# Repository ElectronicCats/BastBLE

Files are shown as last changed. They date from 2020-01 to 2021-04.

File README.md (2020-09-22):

# Bast BLE

Bast BLE is all the best in the world format Feather and BLE with a Nordic NRF!, Feather pin to pin compatible with a USB port type C.

Bast-BLE is supported in the Arduino development environment and Circuit Python coming soon

We love all our Feathers equally, but this Feather is very special. It's our first Feather that is specifically designed for use with CircuitPython! CircuitPython is our beginner-oriented flavor of MicroPython - and as the name hints at, its a small but full-featured version of the popular Python programming language specifically for use with circuitry and electronics.

Please note, CircuitPython does not come preloaded. See the full guide linked below for instructions on installing it

Lipoly battery and USB cable not included (but we do have lots of options in the shop if you'd like!)

## Hardware Features

* Nordic nRF52840 System-on-Chip
	- ARM® Cortex®-M4F processor optimized for ultra-low power operation
	- Combining *Bluetooth 5*, *Bluetooth Mesh*, *Thread*, *IEEE 802.15.4*, *ANT* and *2.4GHz proprietary*
	- On-chip NFC-A tag
	- On-chip USB 2.0 (Full speed) controller
	- ARM TrustZone® Cryptocell 310 security subsystem
	- 1 MB FLASH and 256 kB RAM
* Program/Debug options with DAPLink
	- MSC - drag-n-drop programming flash memory
	- CDC - virtual com port for log, trace and terminal emulation
	- HID - CMSIS-DAP compliant debug channel
	- WEBUSB HID - CMSIS-DAP compliant debug channel
* External ultra-low power 64-Mb QSPI FLASH memory
* Up to 21 GPIOs available via headers
* IF Boot/Reset Button
* On-board 2.4G chip antenna 
* 3.3V regulator with 1A peak current output
* VBUS & VIN Power-Path Management
* Reversible USB 3.1 Type-C Connector
* Breadboard-friendly with dual 18-Pin headers
* Feather Format

## How to get Bast BLE
Bast BLE is available on the following channels (click to go directly to the product):

<a href="https://electroniccats.com/store/nfc-copy-cat/">
  
</a>

## Pinout Diagram
Coming Soon..
[]()

## Software Resource

The nRF52840 Micro Dev Kit USB Dongle can be used to play with : *nRF5 SDK*, *OpenThread*, *Web Bluetooth*, *iBeacon*, *Eddystone*, and more.

| Software  | Brief Description |
| --- | ----- |
| [Arduino Core MbedOS](https://github.com/ElectronicCats/ArduinoCore-mbed) | The friendly Arduino core by Electronic Cats with MbedOS, |
| [UF2 Bootloader](https://github.com/ElectronicCats/Adafruit_nRF52_Bootloader) | UF2 Bootloader fir NRF52, |
| [nRF5 SDK](nrf5-sdk/) | Offical Software Development Kit for nRF51 and nRF52 Series |
| [OpenThread Border Router](OTBR/) | An open source border router, designed to work with OpenThread |
| [Thread Network Sniffer](thread-sniffer/) | Help you to efficiently analyze Thread network traffic|
| [Web Bluetooth](https://webbluetoothcg.github.io/web-bluetooth/) | Bluetooth support for the Web |
| [iBeacon](https://developer.apple.com/ibeacon/) | A Bluetooth low energy advertising message format designed by Apple |
| [Eddystone](https://github.com/google/eddystone) | A protocol specification that defines a Bluetooth low energy message format for proximity beacon messages |
| [CircuitPython](https://github.com/adafruit/circuitpython/blob/master/ports/nrf/README.md) | A Python language for microcontrollers designed to simplify experimentation and learning |
| [TinyGo](https://github.com/tinygo-org/tinygo) | Go compiler for small devices, based on LLVM |
| [Rust for nrf52840-mdk](https://github.com/nrf-rs/nrf52840-mdk-rs) | Rust support for the nrf52840-mdk development board |
| [RIOT OS](https://github.com/RIOT-OS/RIOT/blob/695e91a90a6545b6937bd0f52f0e87d278155ec0/boards/nrf52840-mdk/doc.txt) | The friendly Operating System for the Internet of Things, |

## Contributing

We would love for you to contribute to this project and help make it even better than it is today! 

License

OpenSourceLicense

Electronic Cats invests time and resources providing this open source design, please support Electronic Cats and open-source hardware by purchasing products from Electronic Cats!

Designed by Electronic Cats.

Firmware released under an GNU AGPL v3.0 license. See the LICENSE file for more information.

Hardware released under an CERN Open Hardware Licence v1.2. See the LICENSE_HARDWARE file for more information.

Electronic Cats is a registered trademark, please do not use if you sell these PCBs.

January 2020

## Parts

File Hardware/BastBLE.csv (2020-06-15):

Reference | Quantity | Value | Footprint | Datasheet | manf#
C1 C2 C3 | 3 | 10uF | Capacitor_SMD:C_0603_1608Metric_Pad1.05x0.95mm_HandSolder | ~ | -
C10 C9 | 2 | 22pF | Capacitor_SMD:C_0603_1608Metric_Pad1.05x0.95mm_HandSolder | ~ | 06035A220JAT4A
C4 C5 C6 C7 C8 | 5 | 0.1uF | Capacitor_SMD:C_0603_1608Metric_Pad1.05x0.95mm_HandSolder | ~ | -
D1 | 1 | MBR120 | Diode_SMD:D_SOD-123F | http://www.onsemi.com/pub_link/Collateral/MBR340-D.PDF | MBR120VLSFT3G
D2 D3 | 2 | LED | LED_SMD:LED_0805_2012Metric | ~ | -
J1 | 1 | Battery |  | ~
J2 | 1 | SWD | Connector_PinSocket_2.54mm:PinSocket_1x04_P2.54mm_Vertical | ~
J3 | 1 | Conn_left | Connector_PinHeader_2.54mm:PinHeader_1x16_P2.54mm_Vertical | ~
J4 | 1 | Conn_right | Connector_PinHeader_2.54mm:PinHeader_1x12_P2.54mm_Vertical | ~
L1 | 1 | 10uH | Inductor_SMD:L_0603_1608Metric_Pad1.05x0.95mm_HandSolder | ~
P1 | 1 | USB_C_Plug_USB2.0 | Connectors_ElectronicCats:C393939 | https://www.usb.org/sites/default/files/documents/usb_type-c.zip | MLJ1608WR16JT000
Q1 | 1 | DMG3415U-7 | Package_TO_SOT_SMD:SOT-23 | ~ | DMG3415U-7
R2 R1 R5 R6 | 4 | 100K | Resistor_SMD:R_0603_1608Metric_Pad1.05x0.95mm_HandSolder | ~ | CRCW0603100KFKEAC
R3 | 1 | 4K7 | Resistor_SMD:R_0603_1608Metric_Pad1.05x0.95mm_HandSolder | ~ | SFR03EZPF4701
R4 R7 | 2 | 1K | Resistor_SMD:R_0603_1608Metric_Pad1.05x0.95mm_HandSolder | ~
R8 R9 | 2 | 5K1 | Resistor_SMD:R_0603_1608Metric_Pad1.05x0.95mm_HandSolder | ~ | CRCW06035K10FKEAC
SW1 | 1 | RESET | Button_Switch_SMD:SW_SPST_TL3342 | TS-1185EC-C-D-B | -
U1 | 1 | AP2112K-3.3 | Package_TO_SOT_SMD:SOT-23-5 | https://www.diodes.com/assets/Datasheets/AP2112.pdf | AP2112K-3.3TRG1
U2 | 1 | E73-2G4M08S1C | Rf:E73-2G4M08S1C-52840
U3 | 1 | MCP73831-2-OT | Package_TO_SOT_SMD:SOT-23-5 | http://ww1.microchip.com/downloads/en/DeviceDoc/20001984g.pdf | MCP73831-3-OT
U4 | 1 | W25Q32JVSS | Package_SO:SOIC-8_5.23x5.23mm_P1.27mm | http://www.winbond.com/resource-files/w25q32jv%20revg%2003272018%20plus.pdf | W25Q16JVSNIQ
Y1 | 1 | 32Khz | Crystal:Crystal_SMD_3215-2Pin_3.2x1.5mm | ~ | LFXTAL009678Reel

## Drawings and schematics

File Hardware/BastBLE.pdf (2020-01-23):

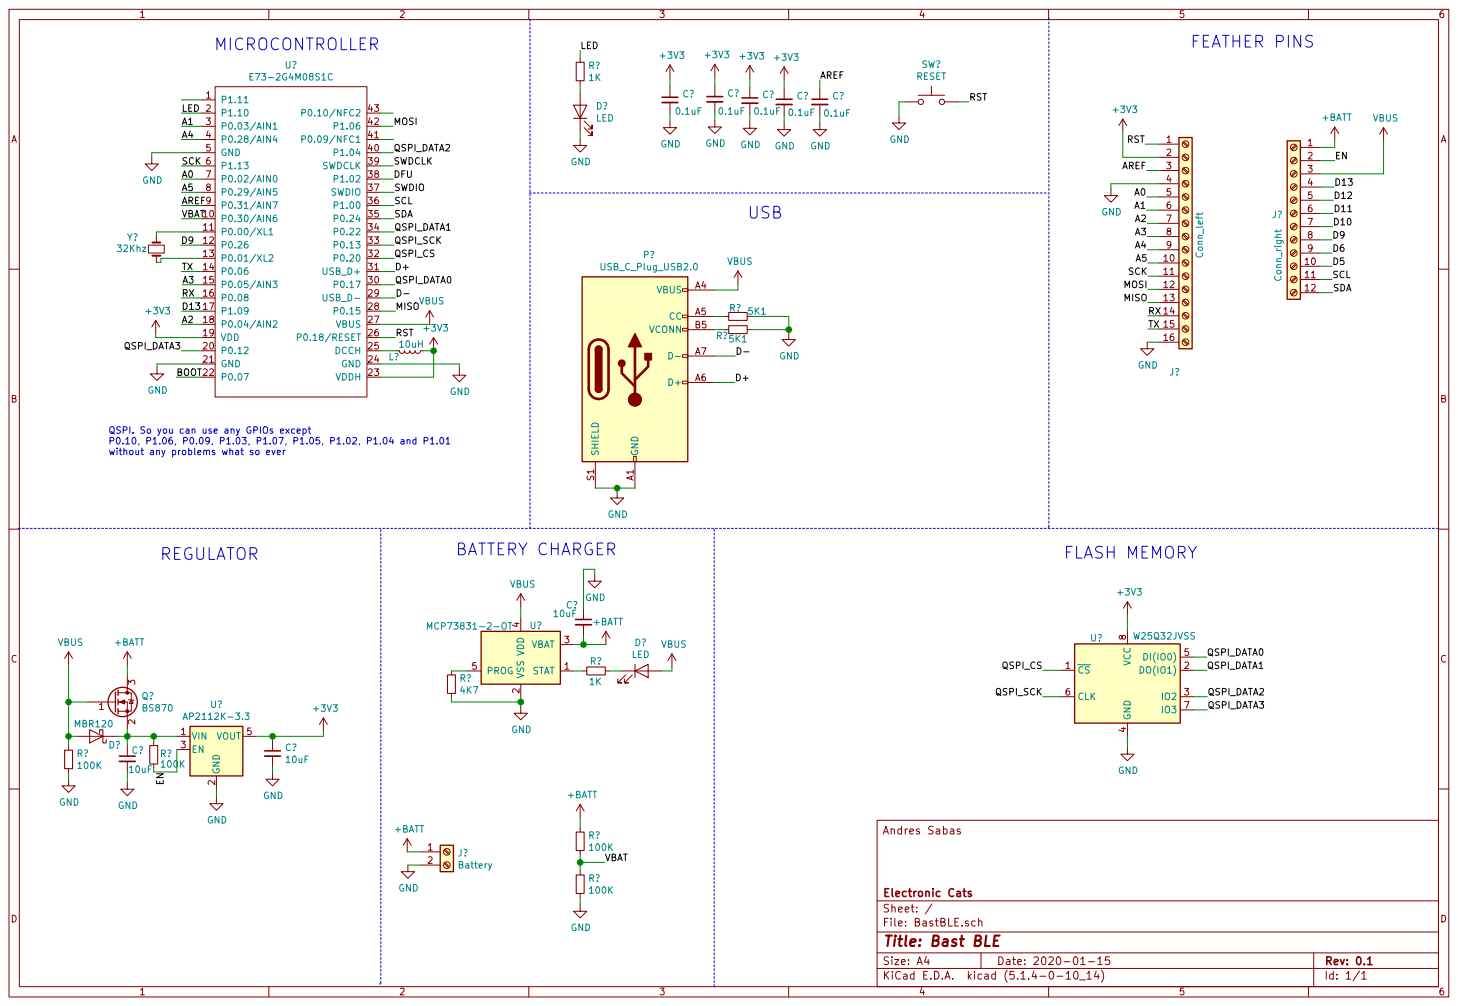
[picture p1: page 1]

LED
RST AREF A5A4A0A3 A2A1 BOOT RX

DFU QSPI. So you can use any GPIOs except P0.10, P1.06, P0.09, P1.03, P1.07, P1.05, P1.02, P1.04 and P1.01 without any problems what so ever

4 PROG 5 MCP73831-2-OT U? VIN 1 GND

File: BastBLE.sch Sheet: / Electronic Cats Andres Sabas

Id: 1/1 Title: Bast BLE

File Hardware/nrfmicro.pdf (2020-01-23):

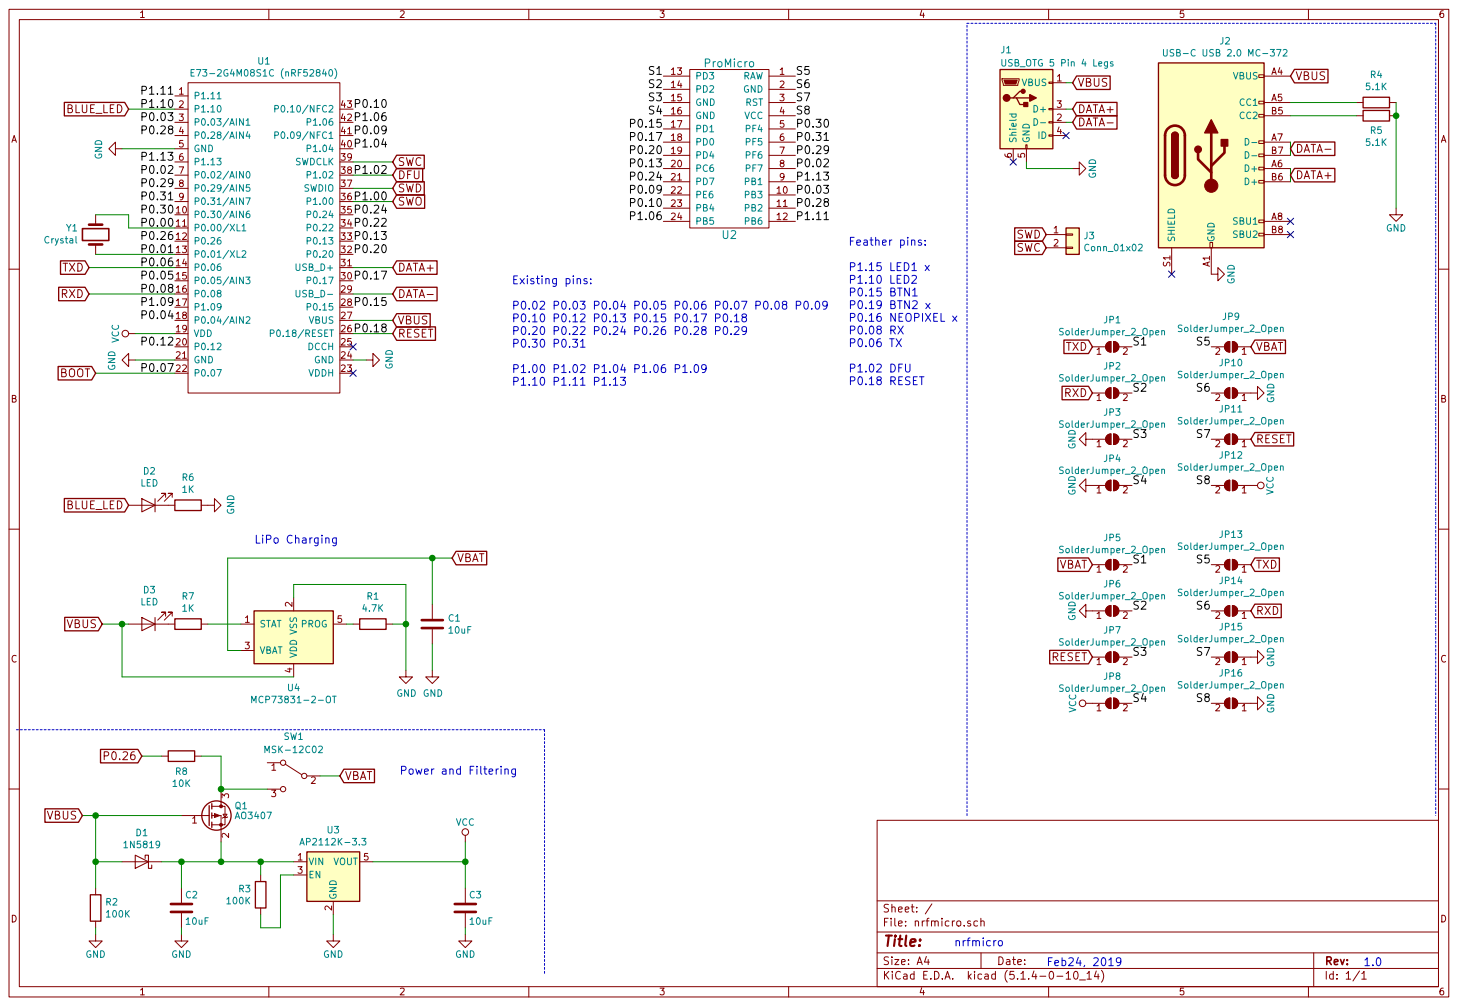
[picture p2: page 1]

4 PROG 5 U4 MCP73831-2-OT GND GND GND 1 2

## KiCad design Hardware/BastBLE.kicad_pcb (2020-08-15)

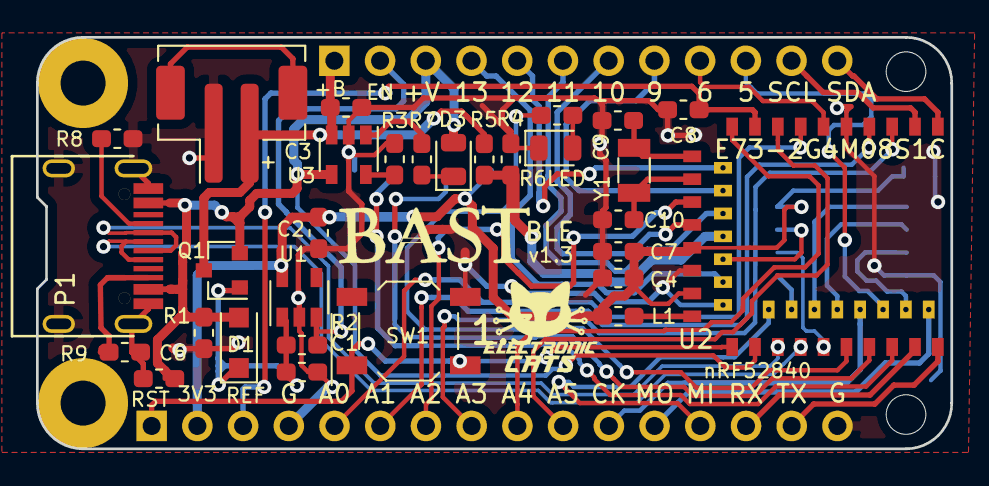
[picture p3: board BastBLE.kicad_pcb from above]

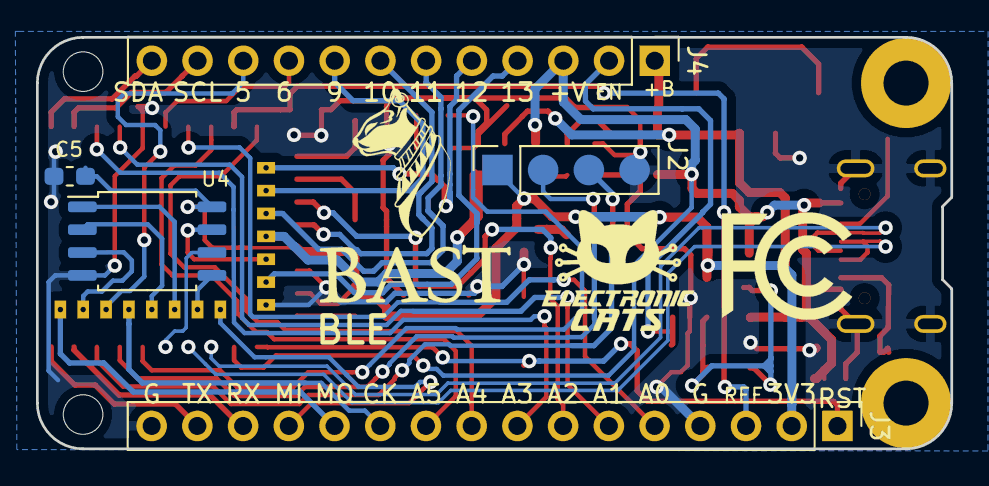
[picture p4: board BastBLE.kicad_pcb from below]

Board: 2 copper layers, 50.8 x 22.9 mm, 35 parts (5 on the bottom side), 49 nets.

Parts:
C1, C2, C3: 10uF; C_0603_1608Metric_Pad1.05x0.95mm_HandSolder
C4, C5, C6, C7, C8: 0.1uF; C_0603_1608Metric_Pad1.05x0.95mm_HandSolder
C9, C10: 22pF; C_0603_1608Metric_Pad1.05x0.95mm_HandSolder
D1: MBR120; D_SOD-123F
D2, D3: LED; LED_0805_2012Metric
J1: Conn_Battery; JST_PH_B2B-PH-SM4-TB_1x02-1MP_P2.00mm_Vertical
J2: SWD; PinSocket_1x04_P2.54mm_Vertical
J3: Conn_left; PinHeader_1x16_P2.54mm_Vertical
J4: Conn_right; PinHeader_1x12_P2.54mm_Vertical
L1: 10uH; L_0603_1608Metric_Pad1.05x0.95mm_HandSolder
P1: USB_C_Plug_USB2.0; C393939
Q1: DMG3415U-7; SOT-23
R1, R2, R5, R6: 100K; R_0603_1608Metric_Pad1.05x0.95mm_HandSolder
R3: 4K7; R_0603_1608Metric_Pad1.05x0.95mm_HandSolder
R4, R7: 1K; R_0603_1608Metric_Pad1.05x0.95mm_HandSolder
R8, R9: 5K1; R_0603_1608Metric_Pad1.05x0.95mm_HandSolder
SW1: RESET; SW_SPST_TL3342
U1: AP2112K-3.3; SOT-23-5
U2: E73-2G4M08S1C; E73-2G4M08S1C-52840
U3: MCP73831-2-OT; SOT-23-5
U4: W25Q32JVSS; SOIC-8_5.23x5.23mm_P1.27mm
Y1: 32Khz; Crystal_SMD_3215-2Pin_3.2x1.5mm

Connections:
+3V3: C2.1, C4.1, C5.1, C7.1, J2.1, J3.2, L1.1, U1.5, U2.19, U2.23, U4.8
+BATT: C3.2, J1.2, J4.1, Q1.3, R5.1, U3.3
/A0: J3.5, U2.7
/A1: J3.6, U2.4
/A2: J3.7, U2.15
/A3: J3.8, U2.3
/A4: J3.9, U2.10
/A5: J3.10, U2.8
/AREF: C8.1, J3.3, U2.9
/D5: J4.10, U2.38
/D6: J4.9, U2.6
/D9: J4.8, U2.14
/D10: J4.7, U2.17
/D11: J4.6, U2.16
/D12: J4.5, U2.12
/D13: J4.4, U2.22
/D+: P1.A6, U2.31
/D-: P1.A7, U2.29
/EN: J4.2, R2.2, U1.3
/LED: R4.1, U2.35
/MISO: J3.13, U2.28
/MOSI: J3.12, U2.42
/QSPI_CS: U2.32, U4.1
/QSPI_DATA0: U2.30, U4.5
/QSPI_DATA1: U2.34, U4.2
/QSPI_DATA2: U2.40, U4.3
/QSPI_DATA3: U2.20, U4.7
/QSPI_SCK: U2.33, U4.6
/RST: J3.1, SW1.2, U2.26
/RX: J3.14, U2.41
/SCK: J3.11, U2.36
/SCL: J4.11, U2.2
/SDA: J4.12, U2.1
/SWCLK: J2.3, U2.39
/SWDIO: J2.2, U2.37
/TX: J3.15, U2.43
/VBAT: R5.2, R6.1, U2.18
GND: C1.2, C2.2, C3.1, C4.2, C5.2, C6.2, C7.2, C8.2, C9.2, C10.2, D2.1, J1.1, J2.4, J3.4, J3.16, P1.A1, P1.S1, R1.2, R3.2, R6.2, R8.1, R9.1, SW1.1, U1.2, U2.5, U2.21, U2.24, U3.2, U4.4
unnamed: C1.1, D1.1, Q1.1, R2.1, U1.1
unnamed: C9.1, U2.11, Y1.1
unnamed: C10.1, U2.13, Y1.2
unnamed: D2.2, R4.2
unnamed: D3.1, R7.1
unnamed: L1.2, U2.25
unnamed: P1.A5, R8.2
unnamed: P1.B5, R9.2
unnamed: R3.1, U3.5
unnamed: R7.2, U3.1
VBUS: C6.1, D1.2, D3.2, J4.3, P1.A4, Q1.2, R1.1, U2.27, U3.4

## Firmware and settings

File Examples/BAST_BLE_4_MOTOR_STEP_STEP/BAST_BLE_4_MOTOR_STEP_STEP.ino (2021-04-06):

int a[200];
int b;
int c;
#include <ArduinoBLE.h>
int x;
int y;
static const char* greeting = "Hello World!";
BLEService greetingService("180C"); 
BLEStringCharacteristic greetingCharacteristic("2A56", BLERead, 13); 
int dato;
BLEService ledService("19B10000-E8F2-537E-4F6C-D104768A1214");
BLEByteCharacteristic switchCharacteristic("19B10001-E8F2-537E-4F6C-D104768A1214", BLERead | BLEWrite);

int paso [4][4] =
{
  {1, 1, 0, 0},
  {0, 1, 1, 0},
  {0, 0, 1, 1},
  {1, 0, 0, 1}
};

int paso2 [4][4] =
{
  {1, 1, 0, 0},
  {0, 1, 1, 0},
  {0, 0, 1, 1},
  {1, 0, 0, 1}
};
int paso3 [4][4] =
{
  {1, 1, 0, 0},
  {0, 1, 1, 0},
  {0, 0, 1, 1},
  {1, 0, 0, 1}
};
int paso4 [4][4] =
{
  {1, 1, 0, 0},
  {0, 1, 1, 0},
  {0, 0, 1, 1},
  {1, 0, 0, 1}
};

void setup() {
  while (!Serial);
  Serial.begin(115200);
  for (x = 2; x <= 13; x++) {
    pinMode(x, OUTPUT);
  }
  for (x = 15; x <= 18; x++) {
    pinMode(x, OUTPUT);
  }
  if (!BLE.begin()) {   
    Serial.println("starting BLE failed!");
    while (1);
  }
 BLE.setLocalName("bast ble ec");  
  BLE.setAdvertisedService(greetingService); 
  greetingService.addCharacteristic(greetingCharacteristic);
  BLE.addService(greetingService);
  greetingCharacteristic.setValue(greeting);
  Serial.print("Peripheral device MAC: ");
  Serial.println(BLE.address());
  Serial.println("esperando coneccion...");

BLE.setAdvertisedService(ledService);
ledService.addCharacteristic(switchCharacteristic);
  BLE.addService(ledService);
  BLE.advertise(); 
  switchCharacteristic.writeValue(0);
}

void loop() {
  BLEDevice central = BLE.central();  
  if (central) {
    Serial.print("Connected to central MAC: ");
    }
    Serial.println(central.address());
    digitalWrite(8, HIGH);
    while (central.connected()){
      if (y == 0){
        if (switchCharacteristic.written()) {
      if (switchCharacteristic.value() == 'O' ) {   // any value other than 0
          Serial.println("GRIPER OPEN"); 
      for (x = 0; x < 15; x++) {
        for (int i = 0; i < 4; i++)
        {
          digitalWrite(15, paso[i][0]);
          digitalWrite(16, paso[i][1]);
          digitalWrite(17, paso[i][2]);
          digitalWrite(18, paso[i][3]);
          delay(5);
        }
      }
        } else if (switchCharacteristic.value() == 'C' ) {   // any value other than 0
      Serial.println("GRIPER CLOCED");
      for (x = 0; x < 15; x++) {
        for (int i = 3; i >= 0; i--)
        {
          digitalWrite(15, paso[i][0]);
          digitalWrite(16, paso[i][1]);
          digitalWrite(17, paso[i][2]);
          digitalWrite(18, paso[i][3]);
          delay(5);
        }
      }
        } else if (switchCharacteristic.value() == 'U' ) {                              // a 0 value
          Serial.println("ARM UP");
     for (x = 0; x < 15; x++) {
        for (int i = 0; i < 4; i++)
        {
          digitalWrite(2, paso2[i][0]);
          digitalWrite(3, paso2[i][1]);
          digitalWrite(5, paso2[i][2]);
          digitalWrite(6, paso2[i][3]);
          delay(5);
        }
      }

        }else if (switchCharacteristic.value() == 'D' ) {                              // a 0 value
          Serial.println("ARM DOWN");
      for (x = 0; x < 15; x++) {
        for (int i = 3; i >= 0; i--)
        {
          digitalWrite(2, paso2[i][0]);
          digitalWrite(3, paso2[i][1]);
          digitalWrite(5, paso2[i][2]);
          digitalWrite(6, paso2[i][3]);
          delay(5);
        }
      }
        }else if (switchCharacteristic.value() == 'A' ) {                              // a 0 value
          Serial.println("BOW UP");
      for (x = 0; x < 15; x++) {
        for (int i = 0; i < 4; i++)
        {
          digitalWrite(10, paso3[i][0]);
          digitalWrite(11, paso3[i][1]);
          digitalWrite(12, paso3[i][2]);
          digitalWrite(13, paso3[i][3]);
          delay(5);
        }
      }
        }else if (switchCharacteristic.value() == 'B' ) {                              // a 0 value
          Serial.println("BOW DOWN");
      for (x = 0; x < 15; x++) {
        for (int i = 3; i >= 0; i--)
        {
          digitalWrite(10, paso3[i][0]);
          digitalWrite(11, paso3[i][1]);
          digitalWrite(12, paso3[i][2]);
          digitalWrite(13, paso3[i][3]);
          delay(5);
        }
      }
        }else if (switchCharacteristic.value() == 'L' ) {                              // a 0 value
          Serial.println("BASE LEFT");
      for (x = 0; x < 15; x++) {
        for (int i = 0; i < 4; i++)
        {
          digitalWrite(19, paso4[i][0]);
          digitalWrite(20, paso4[i][1]);
          digitalWrite(4, paso4[i][2]);
          digitalWrite(7, paso4[i][3]);
          delay(5);
        }
      }
        }else if (switchCharacteristic.value() == 'R' ) {                              // a 0 value
          Serial.println("BASE RIGTH");
      for (x = 0; x < 15; x++) {
        for (int i = 3; i >= 0; i--)
        {
          digitalWrite(19, paso4[i][0]);
          digitalWrite(20, paso4[i][1]);
          digitalWrite(4, paso4[i][2]);
          digitalWrite(7, paso4[i][3]);
          delay(5);
        }
      }
        }else if (switchCharacteristic.value() == 'G' ) {
          // a 0 value
          y = 1;
          b = 0;
          Serial.println(F("RECORDING MOVIMENTS"));
        }else if (switchCharacteristic.value() == 'P' ) {
          // a 0 value
          y = 2;
          b = 0;
          Serial.println("RECORDING MOVIMENTS");
        }
      }
    }
    if (y == 1) {
         if (switchCharacteristic.written()) {
      if (switchCharacteristic.value() == 'O' ) {   // any value other than 0
          Serial.println("GRIPER OPEN");
          a[b] = 'O';
          b++;
      for (x = 0; x < 15; x++) {
        for (int i = 0; i < 4; i++)
        {
          digitalWrite(15, paso[i][0]);
          digitalWrite(16, paso[i][1]);
          digitalWrite(17, paso[i][2]);
          digitalWrite(18, paso[i][3]);
          delay(5);
        }
      }
        } else if (switchCharacteristic.value() == 'C' ) {   // any value other than 0
         Serial.println("GRIPER CLOCE");
          a[b] = 'C';
          b++;
      for (x = 0; x < 15; x++) {
        for (int i = 3; i >= 0; i--)
        {
          digitalWrite(15, paso[i][0]);
          digitalWrite(16, paso[i][1]);
          digitalWrite(17, paso[i][2]);
          digitalWrite(18, paso[i][3]);
          delay(5);
        }
      }
        } else if (switchCharacteristic.value() == 'U' ) {                              // a 0 value
          Serial.println("ARM UP");
          a[b] = 'U';
          b++;
     for (x = 0; x < 15; x++) {
        for (int i = 0; i < 4; i++)
        {
          digitalWrite(2, paso2[i][0]);
          digitalWrite(3, paso2[i][1]);
          digitalWrite(5, paso2[i][2]);
          digitalWrite(6, paso2[i][3]);
          delay(5);
        }
      }

        }else if (switchCharacteristic.value() == 'D' ) {                              // a 0 value
          Serial.println("ARM DOWN");
          a[b] = 'D';
          b++;
      for (x = 0; x < 15; x++) {
        for (int i = 3; i >= 0; i--)
        {
          digitalWrite(2, paso2[i][0]);
          digitalWrite(3, paso2[i][1]);
          digitalWrite(5, paso2[i][2]);
          digitalWrite(6, paso2[i][3]);
          delay(5);
        }
      }
        }else if (switchCharacteristic.value() == 'A' ) {                              // a 0 value
          Serial.println("BOW UP");
          a[b] = 'A';
          b++;
      for (x = 0; x < 15; x++) {
        for (int i = 0; i < 4; i++)
        {
          digitalWrite(10, paso3[i][0]);
          digitalWrite(11, paso3[i][1]);
          digitalWrite(12, paso3[i][2]);
          digitalWrite(13, paso3[i][3]);
          delay(5);
        }
      }
        }else if (switchCharacteristic.value() == 'B' ) {                              // a 0 value
          Serial.println("BOW DOWN");
          a[b] = 'B';
          b++;
      for (x = 0; x < 15; x++) {
        for (int i = 3; i >= 0; i--)
        {
          digitalWrite(10, paso3[i][0]);
          digitalWrite(11, paso3[i][1]);
          digitalWrite(12, paso3[i][2]);
          digitalWrite(13, paso3[i][3]);
          delay(5);
        }
      }
        }else if (switchCharacteristic.value() == 'L' ) {                              // a 0 value
          Serial.println("BASE LEFT");
          a[b] = 'L';
          b++;
      for (x = 0; x < 15; x++) {
        for (int i = 0; i < 4; i++)
        {
          digitalWrite(19, paso4[i][0]);
          digitalWrite(20, paso4[i][1]);
          digitalWrite(4, paso4[i][2]);
          digitalWrite(7, paso4[i][3]);
          delay(5);
        }
      }
        }else if (switchCharacteristic.value() == 'R' ) {                              // a 0 value
          Serial.println("BASE RIGTH");
          a[b] = 'R';
          b++;
      for (x = 0; x < 15; x++) {
        for (int i = 3; i >= 0; i--)
        {
          digitalWrite(19, paso4[i][0]);
          digitalWrite(20, paso4[i][1]);
          digitalWrite(4, paso4[i][2]);
          digitalWrite(7, paso4[i][3]);
          delay(5);
        }
      }
        }else if (switchCharacteristic.value() == 'S' ) {
          // a 0 value
          c = b-1;
          y = 0;
          Serial.println(F("RECORDING MOVIMENTS"));
        }
      }     
      }
      if (y ==2 ){
        for (b=0; b<=c;b++)
        {
          a[b];
          if (a[b]== 'O' ){
              for (x = 0; x < 15; x++) {
                for (int i = 0; i < 4; i++)
                {
                  digitalWrite(15, paso[i][0]);
                  digitalWrite(16, paso[i][1]);
                  digitalWrite(17, paso[i][2]);
                  digitalWrite(18, paso[i][3]);
                  delay(5);
                }
              }            
            }
          if (a[b]== 'C' ){
               for (x = 0; x < 15; x++) {
                for (int i = 3; i >= 0; i--)
                {
                  digitalWrite(15, paso[i][0]);
                  digitalWrite(16, paso[i][1]);
                  digitalWrite(17, paso[i][2]);
                  digitalWrite(18, paso[i][3]);
                  delay(5);
                }
              }           
            }
          if (a[b]== 'U' ){
               for (x = 0; x < 15; x++) {
                  for (int i = 0; i < 4; i++)
                  {
                    digitalWrite(2, paso2[i][0]);
                    digitalWrite(3, paso2[i][1]);
                    digitalWrite(5, paso2[i][2]);
                    digitalWrite(6, paso2[i][3]);
                    delay(5);
                  }
                }            
            }
          if (a[b]== 'D' ){
                for (x = 0; x < 15; x++) {
                  for (int i = 3; i >= 0; i--)
                  {
                    digitalWrite(2, paso2[i][0]);
                    digitalWrite(3, paso2[i][1]);
                    digitalWrite(5, paso2[i][2]);
                    digitalWrite(6, paso2[i][3]);
                    delay(5);
                  }
                }            
            }
          if (a[b]== 'A' ){
              for (x = 0; x < 15; x++) {
                for (int i = 0; i < 4; i++)
                {
                  digitalWrite(10, paso3[i][0]);
                  digitalWrite(11, paso3[i][1]);
                  digitalWrite(12, paso3[i][2]);
                  digitalWrite(13, paso3[i][3]);
                  delay(5);
                }
              }            
            }
          if (a[b]== 'B' ){
              for (x = 0; x < 15; x++) {
                for (int i = 3; i >= 0; i--)
                {
                  digitalWrite(10, paso3[i][0]);
                  digitalWrite(11, paso3[i][1]);
                  digitalWrite(12, paso3[i][2]);
                  digitalWrite(13, paso3[i][3]);
                  delay(5);
                }
              }            
            }
          if (a[b]== 'L' ){
              for (x = 0; x < 15; x++) {
                for (int i = 0; i < 4; i++)
                {
                  digitalWrite(19, paso4[i][0]);
                  digitalWrite(20, paso4[i][1]);
                  digitalWrite(4, paso4[i][2]);
                  digitalWrite(7, paso4[i][3]);
                  delay(5);
                }
              }            
            }
          if (a[b]== 'R' ){
              for (x = 0; x < 15; x++) {
                for (int i = 3; i >= 0; i--)
                {
                  digitalWrite(19, paso4[i][0]);
                  digitalWrite(20, paso4[i][1]);
                  digitalWrite(4, paso4[i][2]);
                  digitalWrite(7, paso4[i][3]);
                  delay(5);
                }
              }            
            }
          }
        for (b=c; b>=0;b--)
        {
          a[b];
          if (a[b]== 'O' ){
              for (x = 0; x < 15; x++) {
                for (int i = 3; i >= 0; i--)
                {
                  digitalWrite(15, paso[i][0]);
                  digitalWrite(16, paso[i][1]);
                  digitalWrite(17, paso[i][2]);
                  digitalWrite(18, paso[i][3]);
                  delay(5);
                }
              }            
            }
          if (a[b]== 'C' ){
                  for (x = 0; x < 15; x++) {
                    for (int i = 0; i < 4; i++)
                    {
                      digitalWrite(15, paso[i][0]);
                      digitalWrite(16, paso[i][1]);
                      digitalWrite(17, paso[i][2]);
                      digitalWrite(18, paso[i][3]);
                      delay(5);
                    }
                  }            
            }
          if (a[b]== 'U' ){
              for (x = 0; x < 15; x++) {
                for (int i = 3; i >= 0; i--)
                {
                  digitalWrite(2, paso2[i][0]);
                  digitalWrite(3, paso2[i][1]);
                  digitalWrite(5, paso2[i][2]);
                  digitalWrite(6, paso2[i][3]);
                  delay(5);
                }
              }      
            }
          if (a[b]== 'D' ){
               for (x = 0; x < 15; x++) {
                  for (int i = 0; i < 4; i++)
                  {
                    digitalWrite(2, paso2[i][0]);
                    digitalWrite(3, paso2[i][1]);
                    digitalWrite(5, paso2[i][2]);
                    digitalWrite(6, paso2[i][3]);
                    delay(5);
                  }
                }            
            }
          if (a[b]== 'A' ){
               for (x = 0; x < 15; x++) {
                for (int i = 3; i >= 0; i--)
                {
                  digitalWrite(10, paso3[i][0]);
                  digitalWrite(11, paso3[i][1]);
                  digitalWrite(12, paso3[i][2]);
                  digitalWrite(13, paso3[i][3]);
                  delay(5);
                }
              }           
            }
          if (a[b]== 'B' ){
               for (x = 0; x < 15; x++) {
                for (int i = 0; i < 4; i++)
                {
                  digitalWrite(10, paso3[i][0]);
                  digitalWrite(11, paso3[i][1]);
                  digitalWrite(12, paso3[i][2]);
                  digitalWrite(13, paso3[i][3]);
                  delay(5);
                }
              }           
            }
          if (a[b]== 'L' ){
              for (x = 0; x < 15; x++) {
                for (int i = 3; i >= 0; i--)
                {
                  digitalWrite(19, paso4[i][0]);
                  digitalWrite(20, paso4[i][1]);
                  digitalWrite(4, paso4[i][2]);
                  digitalWrite(7, paso4[i][3]);
                  delay(5);
                }
              }            
            }
          if (a[b]== 'R' ){
                for (x = 0; x < 15; x++) {
                  for (int i = 0; i < 4; i++)
                  {
                    digitalWrite(19, paso4[i][0]);
                    digitalWrite(20, paso4[i][1]);
                    digitalWrite(4, paso4[i][2]);
                    digitalWrite(7, paso4[i][3]);
                    delay(5);
                  }
                }            

      if (switchCharacteristic.written()) {
      if (switchCharacteristic.value() == 'S' ) {
        y=0;
        b=0;
        }
      }
      
      }
          }
        }
      } 
    digitalWrite(8, LOW);
    Serial.print("Disconnected from central MAC: ");
    Serial.println(central.address());
}

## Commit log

2020-02-01 assigned pinout complete
    [BastBLE.sch]
2020-02-01 SWD pinout ok, assigned mosfet
    [BastBLE.sch]
2020-02-09 Format adafruit in PCB, init BOM
    [BastBLE.kicad_pcb, BastBLE.sch]
2020-02-11 init assignament footprints
    [BastBLE.kicad_pcb, BastBLE.sch]
2020-02-19 Review PCB
    [BastBLE.sch]
2020-03-14 change L1 package
    [BastBLE.kicad_pcb, BastBLE.sch]
2020-03-26 fix failed components and tracks
    [BastBLE.kicad_pcb]
2020-03-27 routeo signals
    [BastBLE.kicad_pcb]
2020-03-28 Communication miso, mosi, tx, rx
    [BastBLE.kicad_pcb]
2020-03-30 Routeo a4 a5, fix sck mosi
    [BastBLE.kicad_pcb]
2020-03-30 fix c8, r6, and pin
    [BastBLE.kicad_pcb]
2020-04-14 change pins schematic
    [BastBLE.kicad_pcb, BastBLE.sch]
2020-04-15 change routeo
    [BastBLE.kicad_pcb]
2020-04-20 routeo D
    [BastBLE.kicad_pcb]
2020-04-22 chenge analog signals routeo
    [BastBLE.kicad_pcb]
2020-04-23 A0 rf
    [BastBLE.kicad_pcb]
2020-04-24 erase traces, add note
    [BastBLE.kicad_pcb, BastBLE.sch]
2020-04-24 add crystal and fix analogs
    [BastBLE.kicad_pcb, BastBLE.sch]
2020-05-04 add footprint and netlist
    [BastBLE.kicad_pcb, BastBLE.sch]
2020-05-05 fix components
    [BastBLE.kicad_pcb]
2020-05-05 C6 VBUS
    [BastBLE.kicad_pcb, BastBLE.sch]
2020-05-06 D- D+
    [BastBLE.kicad_pcb, BastBLE.sch]
2020-05-07 Flash memory
    [BastBLE.kicad_pcb]
2020-05-07 change pin SDA SCL
    [BastBLE.kicad_pcb, BastBLE.sch]
2020-05-08 fix traces
    [BastBLE.kicad_pcb, BastBLE.sch]
2020-05-08 tracks u2
    [BastBLE.kicad_pcb]
2020-05-08 VBUS and batt
    [BastBLE.kicad_pcb]
2020-05-12 A1 change cap vbus
    [BastBLE.kicad_pcb]
2020-05-12 tracks y1
    [BastBLE.kicad_pcb]
2020-05-20 first routing
    [BastBLE.kicad_pcb, BastBLE.sch]
2020-05-20 added logos and pinout
    [BastBLE.kicad_pcb]
2020-05-20 label 6 fix
    [BastBLE.kicad_pcb]
2020-05-21 fix groudn traces and labels
    [BastBLE.kicad_pcb]
2020-07-11 VBA and D12 exchanged and routed.
    [BastBLE.kicad_pcb, BastBLE.sch]
2020-07-11 fix logo and connector swd
    [BastBLE.kicad_pcb]
2020-07-14 AREF routed
    [BastBLE.kicad_pcb, BastBLE.sch]
2020-07-16 Add logos fix gnd
    [BastBLE.kicad_pcb]
2020-07-19 change memory GD25Q16C
    [BastBLE.sch]
2020-07-27 Ground label fixed
    [BastBLE.kicad_pcb]
2021-01-23 error in app fixed and actualization of the code for arduino
    [BAST_BLE_4_MOTOR_STEP_STEP.ino]
2021-04-01 Update apk android
    New App for project robot arm BLE
